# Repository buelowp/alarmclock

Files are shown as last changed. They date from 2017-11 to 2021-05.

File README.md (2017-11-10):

# alarmclock

A Particle project named alarmclock

## Welcome to your project!

Every new Particle project is composed of 3 important elements that you'll see have been created in your project directory for alarmclock.

#### ```/src``` folder:  
This is the source folder that contains the firmware files for your project. It should *not* be renamed. 
Anything that is in this folder when you compile your project will be sent to our compile service and compiled into a firmware binary for the Particle device that you have targeted.

If your application contains multiple files, they should all be included in the `src` folder. If your firmware depends on Particle libraries, those dependencies are specified in the `project.properties` file referenced below.

#### ```.ino``` file:
This file is the firmware that will run as the primary application on your Particle device. It contains a `setup()` and `loop()` function, and can be written in Wiring or C/C++. For more information about using the Particle firmware API to create firmware for your Particle device, refer to the [Firmware Reference](https://docs.particle.io/reference/firmware/) section of the Particle documentation.

#### ```project.properties``` file:  
This is the file that specifies the name and version number of the libraries that your project depends on. Dependencies are added automatically to your `project.properties` file when you add a library to a project using the `particle library add` command in the CLI or add a library in the Desktop IDE.

## Adding additional files to your project

#### Projects with multiple sources
If you would like add additional files to your application, they should be added to the `/src` folder. All files in the `/src` folder will be sent to the Particle Cloud to produce a compiled binary.

#### Projects with external libraries
If your project includes a library that has not been registered in the Particle libraries system, you should create a new folder named `/lib/<libraryname>/src` under `/<project dir>` and add the `.h` and `.cpp` files for your library there. All contents of the `/lib` folder and subfolders will also be sent to the Cloud for compilation.

## Compiling your project

When you're ready to compile your project, make sure you have the correct Particle device target selected and run `particle compile <platform>` in the CLI or click the Compile button in the Desktop IDE. The following files in your project folder will be sent to the compile service:

- Everything in the `/src` folder, including your `.ino` application file
- The `project.properties` file for your project
- Any libraries stored under `lib/<libraryname>/src`

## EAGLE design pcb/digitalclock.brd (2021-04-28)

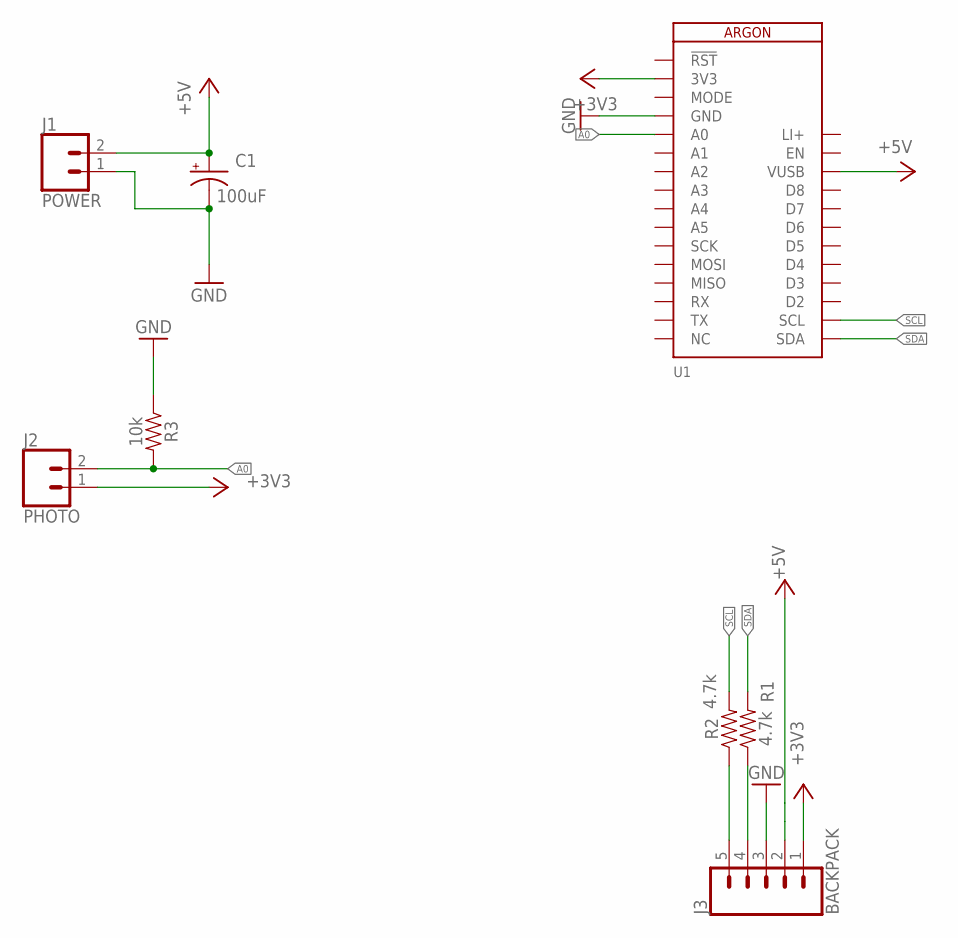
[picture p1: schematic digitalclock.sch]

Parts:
C1: 100uF; CPOL-RADIAL-2.5MM-6.5MM
J1: POWER; 1X02
J2: PHOTO; 1X02
J3: BACKPACK; 1X05
R1, R2: 4.7k; AXIAL-0.3
R3: 10k; AXIAL-0.3
U1: ARGON

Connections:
+3V3: J2.1, J3.1, U1.2 (3V3)
+5V: C1.1 (+), J1.2, J3.2, U1.26 (VUSB)
A0: J2.2, R3.P$2 (2), U1.5 (A0)
GND: C1.2 (-), J1.1, J3.3, R3.P$1 (1), U1.4 (GND)
LI+: U1.28 (LI+)
unnamed: J3.5, R2.P$1 (1)
unnamed: J3.4, R1.P$1 (1)
SCL: R2.P$2 (2), U1.18 (SCL)
SDA: R1.P$2 (2), U1.17 (SDA)

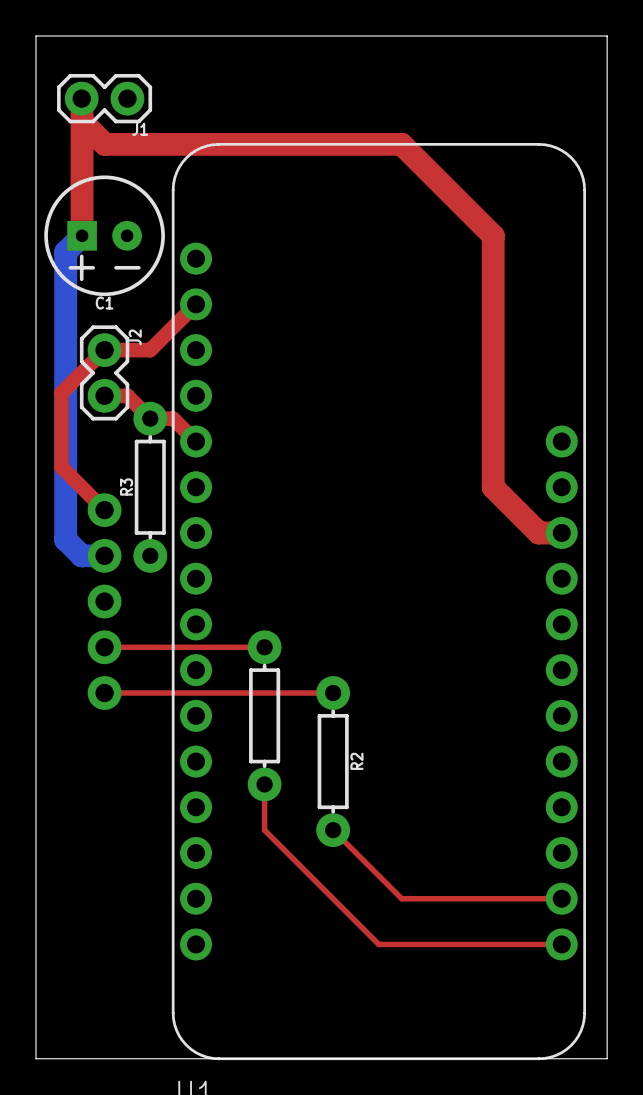
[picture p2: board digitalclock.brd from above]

Board: 2 copper layers, 31.7 x 56.8 mm, 8 parts (1 on the bottom side), 8 nets.

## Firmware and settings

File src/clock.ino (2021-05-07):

#include "sunset.h"
#include "Adafruit_LEDBackpack_RK.h"
#include "MQTT.h"

#define APP_ID              13
#define CST_OFFSET          -6
#define DST_OFFSET          (CST_OFFSET + 1)
#define TIME_BASE_YEAR		2021

#define SUNNY               0
#define RAINY               1
#define SNOWY               2
#define WINDY               3
#define CLOUDY              4

#define LATITUDE        41.12345
#define LONGITUDE       -87.98765

const uint8_t _usDSTStart[22] = { 14,13,12,10, 9, 8,14,12,11,10, 9,14,13,12,11, 9};
const uint8_t _usDSTEnd[22]   = { 7, 6, 5, 3, 2, 1, 7, 5, 4, 3, 2, 7, 6, 5, 4, 2};
String g_name = "iclock-";
String g_mqttName = g_name + System.deviceID().substring(0, 8);
char mqttServer[] = "172.24.1.13";
int g_timeZone;
int g_weather;
int g_brightness;
int g_ledBright;
int g_appid;
String g_conditions;
String g_version;

SunSet sun;
Adafruit_7segment mainclock = Adafruit_7segment();
Adafruit_AlphaNum4 temperature = Adafruit_AlphaNum4();
Adafruit_AlphaNum4 humidity = Adafruit_AlphaNum4();

MQTT client(mqttServer, 1883, callback);
SerialLogHandler logHandler;

int currentTimeZone()
{
    g_timeZone = DST_OFFSET;
    if (Time.month() > 3 && Time.month() < 11) {
        return DST_OFFSET;
    }
    if (Time.month() == 3) {
        if ((Time.day() == _usDSTStart[Time.year() - TIME_BASE_YEAR]) && Time.hour() >= 2)
            return DST_OFFSET;
        if (Time.day() > _usDSTStart[Time.year() - TIME_BASE_YEAR])
            return DST_OFFSET;
    }
    if (Time.month() == 11) {
        if ((Time.day() == _usDSTEnd[Time.year() - TIME_BASE_YEAR]) && Time.hour() <=2)
            return DST_OFFSET;
        if (Time.day() < _usDSTEnd[Time.year() - TIME_BASE_YEAR])
            return DST_OFFSET;
    }
    g_timeZone = CST_OFFSET;
    return CST_OFFSET;
}

//{"environment":{"celsius":17.44,"farenheit":63.42799,"humidity":33.2965,"dewpointc":0.996169,"dewpointf":33.79311,"hourlyrain":0,"raintoday":0,"raintotal":22},"appid":109,"time":1616428681}
void callback(char* leftic, byte* payload, unsigned int length) 
{
    int temp = 0;
    int humid = 0;
    char p[length + 1];
    memcpy(p, payload, length);
    p[length] = '\0';

    JSONValue outerObj = JSONValue::parseCopy(p);
    JSONObjectIterator iter(outerObj);
    while (iter.next()) {
        if (iter.value().isObject() && iter.name() == "environment") {
            JSONObjectIterator env(iter.value());
            while (env.next()) {
                if (env.name() == "farenheit") {
                    temp = static_cast<int>((env.value().toDouble() + .05) * 10);
                }
                if (env.name() == "humidity") {
                    humid = static_cast<int>((env.value().toDouble() + .05) * 10);
                }
            }
        }
    }
    if (temp >= 1000) {
        temperature.writeDigitAscii(0, 49);
        temp -= 1000;
    }
    uint8_t thigh = temp / 100;
    uint8_t tlow = (temp % 100) / 10;
    uint8_t tdec = temp % 10;
    Log.printf("Parsed temp: %d%d.%d\n", thigh, tlow, tdec);

    temperature.writeDigitAscii(1, 48 + thigh);
    temperature.writeDigitAscii(2, 48 + tlow, true);
    temperature.writeDigitAscii(3, 48 + tdec);
    temperature.writeDisplay();
    if (humid >= 1000) {
        humidity.writeDigitAscii(0, 49);
        humid -= 1000;
    }
    uint8_t hhigh = humid / 100;
    uint8_t hlow = (humid % 100) / 10;
    uint8_t hdec = humid % 10;
    Log.printf("Parsed humidity: %d%d.%d\n", hhigh, hlow, hdec);

    humidity.writeDigitAscii(1, 48 + hhigh);
    humidity.writeDigitAscii(2, 48 + hlow, true);
    humidity.writeDigitAscii(3, 48 + hdec);
    humidity.writeDisplay();
}

void connect_mqtt()
{
    client.connect(g_mqttName);

    // publish/subscribe
    if (client.isConnected()) {
        client.subscribe("weather/conditions");
    }
}

void updateClock()
{
    int currenttime = 0;
    
    currenttime = Time.hour() * 100;
    if (currenttime > 1200)
        currenttime -= 1200;

    currenttime += Time.minute();
    mainclock.print(currenttime, DEC);
    mainclock.drawColon(true);
    mainclock.writeDisplay();
}

void clearDisplays()
{
    Serial.begin(115200);
    
    mainclock.clear();
    temperature.clear();
    humidity.clear();

    mainclock.writeDisplay();
    temperature.writeDisplay();
    humidity.writeDisplay();

}

void setBrightness(int bright)
{
    int clock = bright;
    int temp = bright - 6;

    mainclock.setBrightness(clock);
    mainclock.writeDisplay();
    temperature.setBrightness(temp);
    temperature.writeDisplay();
    humidity.setBrightness(temp);
    humidity.writeDisplay();
}

void setDateTime()
{
    int tzoffset = currentTimeZone();

    Particle.syncTime();
    waitUntil(Particle.syncTimeDone);
    sun.setCurrentDate(Time.year(), Time.month(), Time.day());
    sun.setTZOffset(tzoffset);
    Time.zone(tzoffset);
}

void setup()
{
    g_appid = APP_ID;
    g_version = System.version() + "." + g_appid;

    connect_mqtt();
    mainclock.begin(0x70);
    temperature.begin(0x71);
    humidity.begin(0x72);
    clearDisplays();

    Particle.variable("brightness", g_brightness);
    Particle.variable("display", g_ledBright);
    Particle.variable("version", g_version);
    Particle.variable("timezone", g_timeZone);

    sun.setPosition(LATITUDE, LONGITUDE, currentTimeZone());
}

void loop() 
{
    static int lasthour = 24;
    static int lastSecond = 60;

    g_brightness = analogRead(A5);
    g_ledBright = map(g_brightness, 0, 4095, 7, 13);

    setBrightness(g_ledBright);

    if (Time.hour() != lasthour) {
        setDateTime();
        lasthour = Time.hour();
    }

    if (lastSecond != Time.second()) {
        if (client.isConnected()) {
            client.loop();
        }
        else {
            connect_mqtt();
        }
        lastSecond = Time.second();
        updateClock();
    }
}

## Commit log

2017-11-10 Got it working now. Next up, put it in a case.
2017-11-10 Fixed some bugs
    * Updated when I call the timezone update
    * Added some prints to verify it's not always asking for time
2021-04-28 Fixups
    * Add temp/humidity to the clock
    * Update PCB for the connections
    * Start DST settings in 2021
    [digitalclock.brd, digitalclock.sch]
2021-05-07 Fixing up and removing old dead code
    * New range for brightness
    * Remove old code
    [clock.ino]

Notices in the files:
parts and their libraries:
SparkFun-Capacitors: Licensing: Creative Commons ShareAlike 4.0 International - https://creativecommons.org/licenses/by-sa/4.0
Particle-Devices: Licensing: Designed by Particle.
